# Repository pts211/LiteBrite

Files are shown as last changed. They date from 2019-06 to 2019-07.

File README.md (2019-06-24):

# LiteBrite

LiteBrite is a project created for Cerner's DevCon 2019. Its original purpose was to be an interactive piece at the conference for spectators to play with. In throwing around ideas it was determined we could build something that would allow for more uses in the future. This LiteBrite is more of an interactive display. 

# Contributers
  - Paul Sites (paul.sites@cerner.com)
  - Aaron Kaplan (aaron.kaplan@cerner.com)
 
  The Lee's Summit North FIRST Robotics team, The Broncobots:
  - Joshua Wentworth
  - Chuck Stephenson
 
  Good friend
  - James Sietz
  
  Cerner Associates
  - Hans Perera
  - Max Phillips
  - Caitie Oder
  - ... and more!

# Features
- Animated erasing 
- Ripple effect
- Image Viewer
- Desktop display
- Save/Load Designs
- Usage Recorder
- Playback of timelapsed usage
- Screensaver/power save
- e1.31 support (TBD)
- Idle notifications (TBD)
- "Button Mash" mini-game (TBD)
- Clock (TBD)

# Design Details
LiteBrite features:
- 912 individually addressible RGB LED's
- 912 Arcade buttons
- 24 Arduino Nano's
- 24 Custom 40 input circuit boards
- 3 Adafruit FadeCandy boards
- Unmanaged network switch
- Interactivity handled through Processing.

# Usage Details
- DevCon: 111,314 presses (60,912; 50, 402)
- Maker Faire: 332,135 presses (188,901; 143,234)

Lifetime: 443,449 peg presses!

# Acknowledgements
Paul Sites and Aaron Kaplan designed, manufactured, and built LiteBrite but it was only possible with a lot of support, both from inside and outside of Cerner. 

Special thanks to Joshua Wentworth, for working tirelessly alongside us the entire step of the way.

... TODO .. Add it all up

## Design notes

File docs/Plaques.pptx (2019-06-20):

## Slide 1

LiteBrite

Designed and built by Cerner Engineers with support from FRC Team #1987 for DevCon. DevCon is an annual engineering conference Cerner holds for associates to gather and share knowledge.

Click the clear button to start fresh
Press on pegs to change the color

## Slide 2

LiteBrite

  - 38 x 24 pixel arrangement (912 pixels total)
  - 5,472 hand soldered connections
  - 2,736 hand crimped connections
  - 14 days of 24/7 3d printing
  - 2,826 feet of wire
  - 912 arcade buttons
  - 238 feet of acrylic
  - 24 Arduino nano’s with ethernet shields
  - 24 custom designed PCB's
  - Custom welded frame
  - 2x unmanaged 16 port switches
  - Draws nearly 60A @ 5V when full white!
  - Designed to be used to interactively create images. However, can also load images, GIFs, and videos for display.

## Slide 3

Designed by
Paul Sites paul.sites@cerner.com
Aaron Kaplan aaron.kaplan@cerner.com
Joshua Wentworth
Built with help from
Nick Behrens nick.behrens@cerner.com
Pui Lam Cheng puilam.cheng@cerner.com
Miguel Fernandez miguel.fernandez@cerner.com
Taariq Imami taariq.imami@cerner.com
Caitie Oder caitie.oder@cerner.com
Hans Perera hans.perera@cerner.com
Max Philips max.philips@cerner.com
James Sietz
Jonathan Smith jonathan.smith@cerner.com
Melanie Taylor melanie.taylor@cerner.com
Christopher Thomas christopher.thomas@cerner.com
Brandon Wong brandon.wong@cerner.com

## Special Thanks

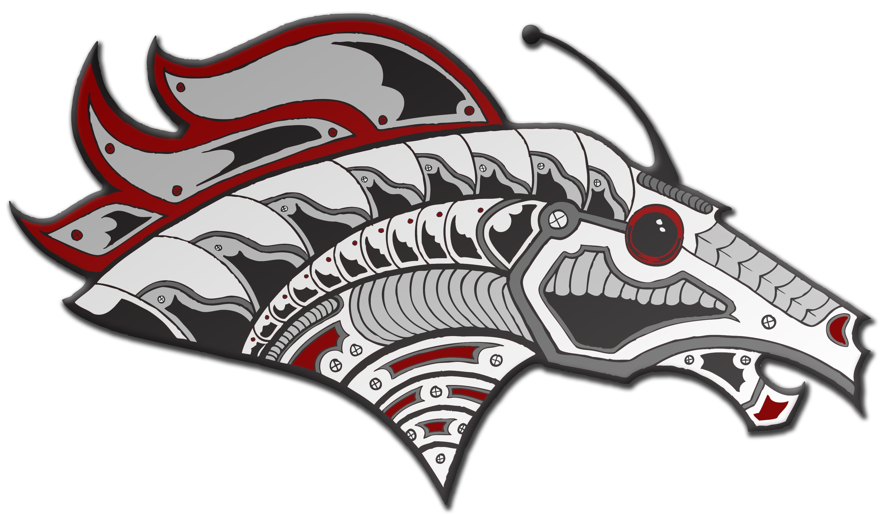
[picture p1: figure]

The Broncobots
FIRST Robotics Team #1987

For opening their robotics shop to build in, providing the tools and equipment necessary to manufacture, and team members to help with assembly.
www.teambroncobots.com

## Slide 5

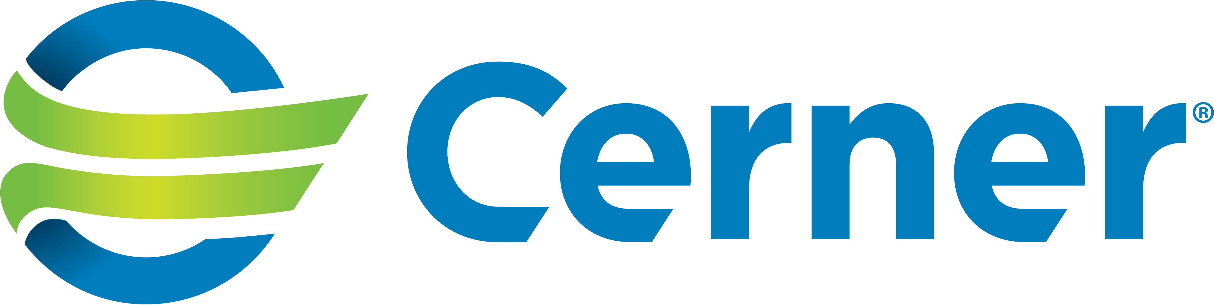
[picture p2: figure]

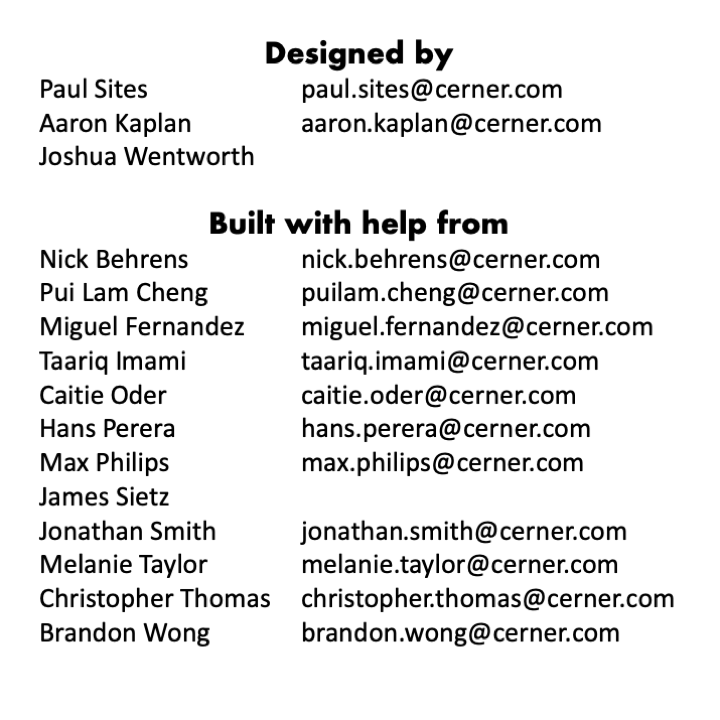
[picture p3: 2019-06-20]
docs/Plaques_updated/Plaques/Slide3.png

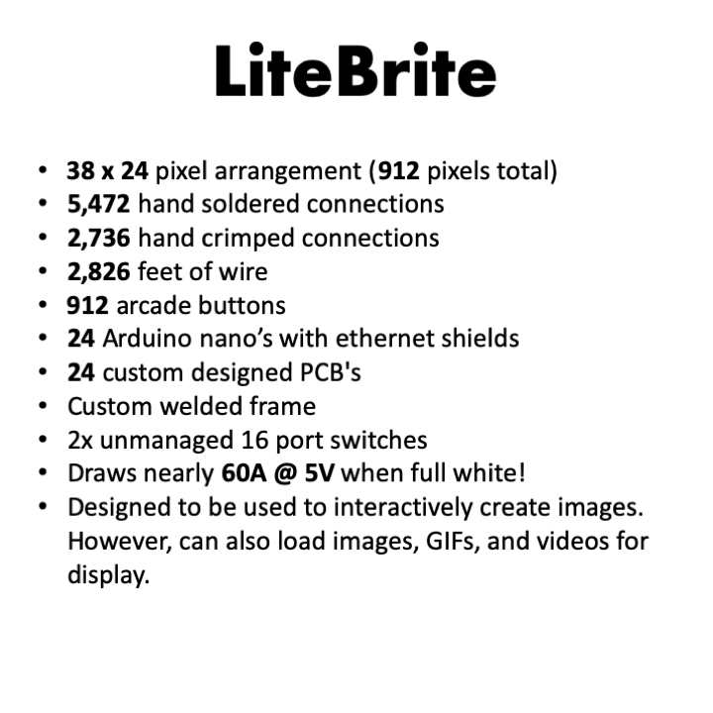
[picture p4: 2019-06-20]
docs/Plaques_updated/Plaques/Slide2.png

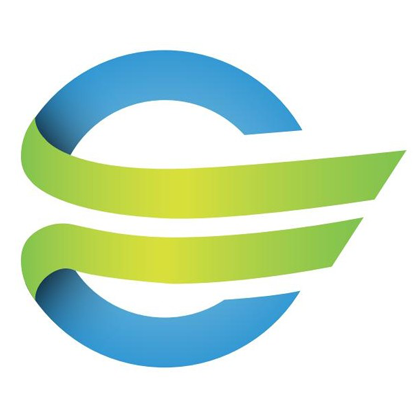
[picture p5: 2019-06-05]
Processing/ProcessingController/images/cern.png

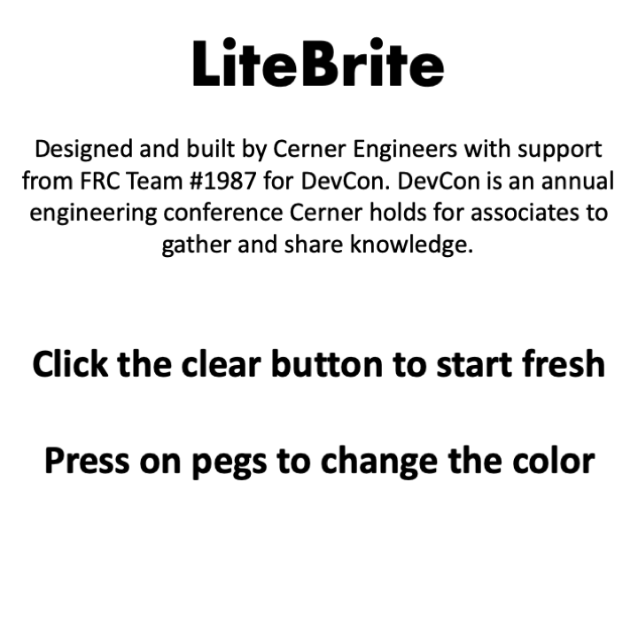
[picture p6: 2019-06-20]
docs/Plaques_updated/Plaques/Slide1.png

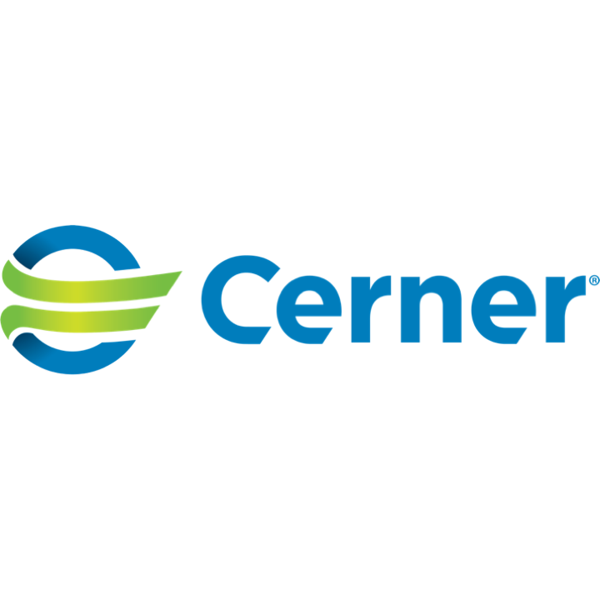
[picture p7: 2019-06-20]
docs/Plaques_updated/Plaques/Slide5.png

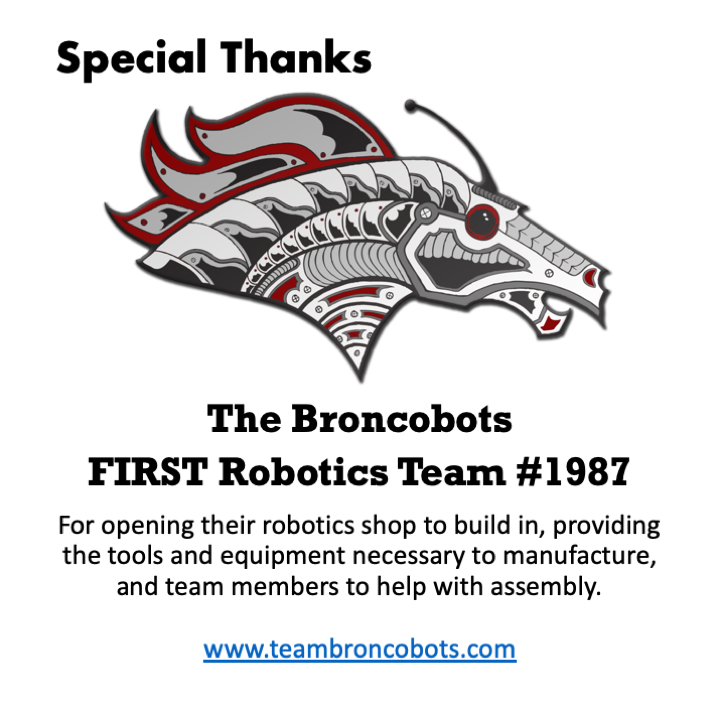
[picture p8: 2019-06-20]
docs/Plaques_updated/Plaques/Slide4.png

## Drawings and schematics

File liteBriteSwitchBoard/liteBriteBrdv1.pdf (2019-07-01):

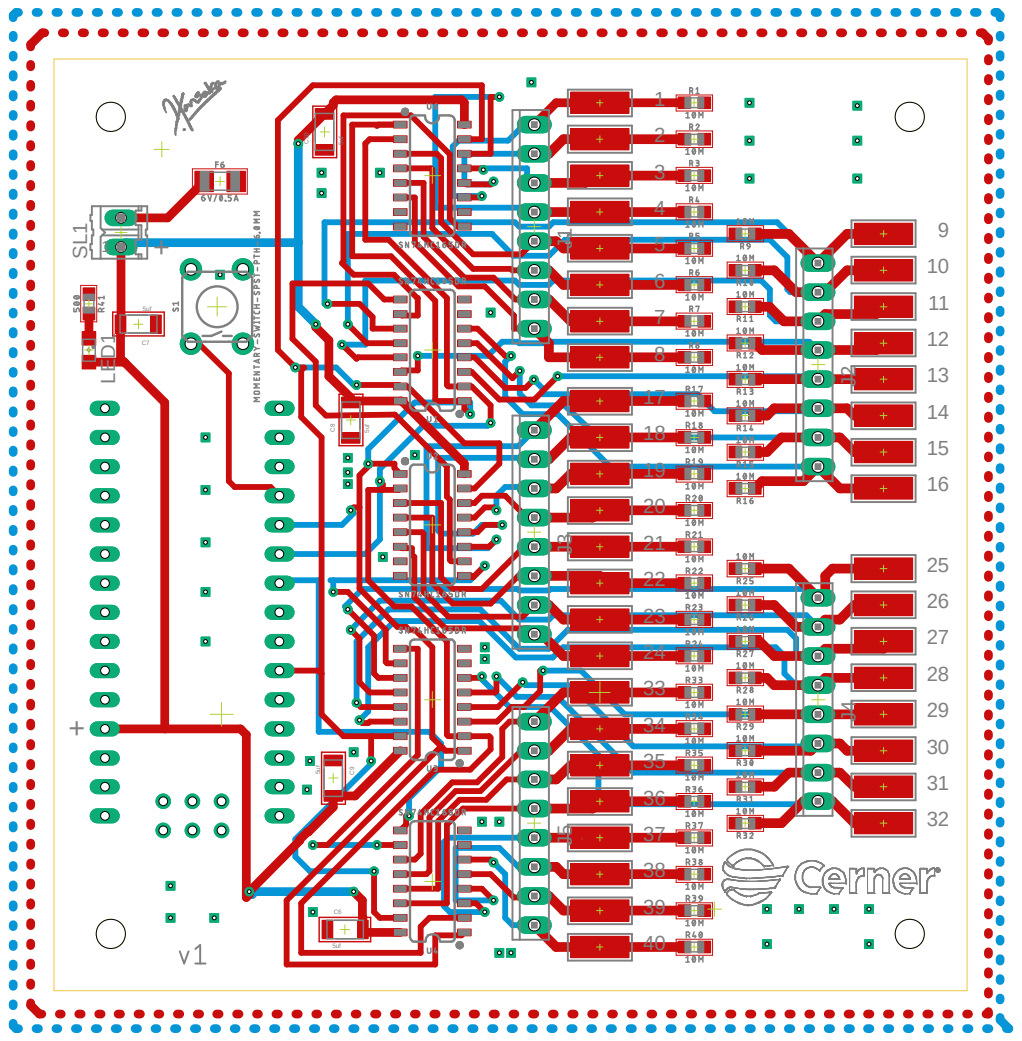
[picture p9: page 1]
343 C¹⁰; J4 J5 LED¹

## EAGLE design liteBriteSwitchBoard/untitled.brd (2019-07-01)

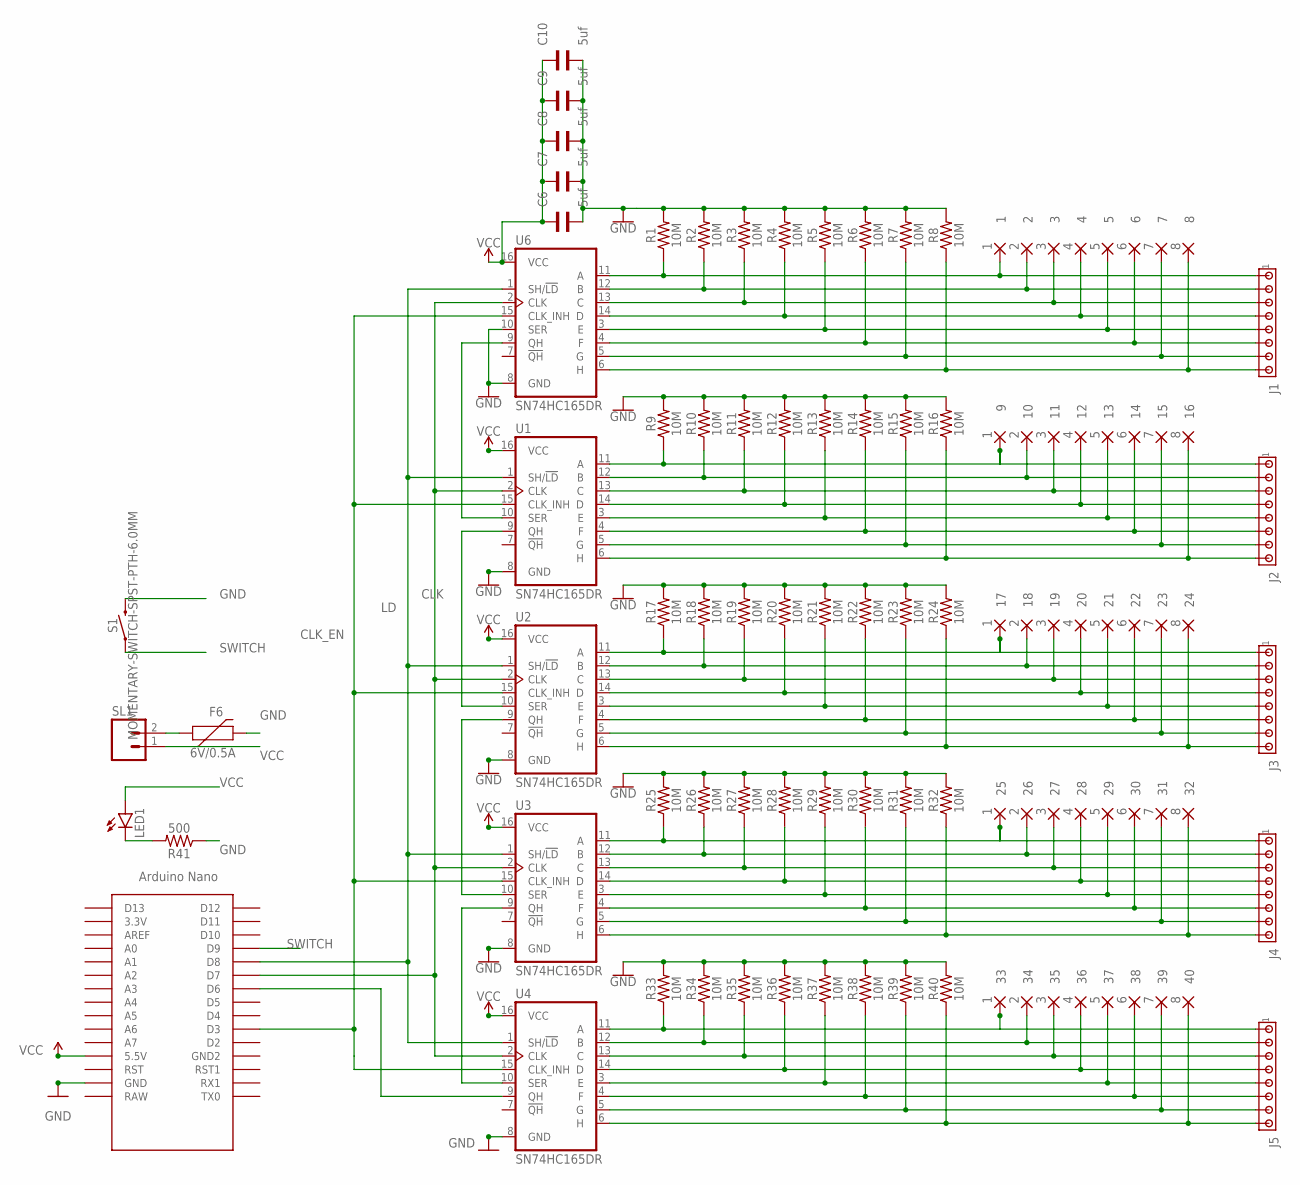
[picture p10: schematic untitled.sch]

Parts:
1, 9, 17, 25, 33: 1; 5-1,8
2, 10, 18, 26, 34: 2; 5-1,8
3, 11, 19, 27, 35: 3; 5-1,8
4, 12, 20, 28, 36: 4; 5-1,8
5, 13, 21, 29, 37: 5; 5-1,8
6, 14, 22, 30, 38: 6; 5-1,8
7, 15, 23, 31, 39: 7; 5-1,8
8, 16, 24, 32, 40: 8; 5-1,8
C6, C7, C8, C9, C10: 5uf; WCAP-CSGP_1206
F6: 6V/0.5A; 1206
J1, J2, J3, J4, J5: MTA08-100; 10X08MTA
LED1: LEDSML0805; SML0805
R1, R2, R3, R4, R5, R6, R7, R8, R9, R10, R11, R12, R13, R14, R15, R16, R17, R18, R19, R20, R21, R22, R23, R24, R25, R26, R27, R28, R29, R30, R31, R32, R33, R34, R35, R36, R37, R38, R39, R40: 10M; 0603
R41: 500; 0603
S1: MOMENTARY-SWITCH-SPST-PTH-6.0MM; TACTILE_SWITCH_PTH_6.0MM
SL1: M02; 02P
U1, U2, U3, U4, U6: SN74HC165DR; SO16
U$1: NANO

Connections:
B1: 2.1, J1.2, R2.1, U6.12 (B)
C1: 3.1, J1.3, R3.1, U6.13 (C)
CLK: U1.2 (CLK), U2.2 (CLK), U3.2 (CLK), U4.2 (CLK), U6.2 (CLK), U$1.D7
CLK_EN: U1.15 (CLK_INH), U2.15 (CLK_INH), U3.15 (CLK_INH), U4.15 (CLK_INH), U6.15 (CLK_INH), U$1.D3
D1: 4.1, J1.4, R4.1, U6.14 (D)
E1: 5.1, J1.5, R5.1, U6.3 (E)
F1: 6.1, J1.6, R6.1, U6.4 (F)
G1: 7.1, J1.7, R7.1, U6.5 (G)
GND: C6.1, C7.1, C8.1, C9.1, C10.1, F6.2, R1.2, R2.2, R3.2, R4.2, R5.2, R6.2, R7.2, R8.2, R9.2, R10.2, R11.2, R12.2, R13.2, R14.2, R15.2, R16.2, R17.2, R18.2, R19.2, R20.2, R21.2, R22.2, R23.2, R24.2, R25.2, R26.2, R27.2, R28.2, R29.2, R30.2, R31.2, R32.2, R33.2, R34.2, R35.2, R36.2, R37.2, R38.2, R39.2, R40.2, R41.1, S1.3 (2), U1.8 (GND), U2.8 (GND), U3.8 (GND), U4.8 (GND), U6.8 (GND), U6.10 (SER), U$1.GND
H1: 8.1, J1.8, R8.1, U6.6 (H)
LD: U1.1 (SH/!LD), U2.1 (SH/!LD), U3.1 (SH/!LD), U4.1 (SH/!LD), U6.1 (SH/!LD), U$1.D8
unnamed: U1.10 (SER), U6.9 (QH)
unnamed: U1.9 (QH), U2.10 (SER)
unnamed: U2.9 (QH), U3.10 (SER)
unnamed: U3.9 (QH), U4.10 (SER)
unnamed: 1.1, J1.1, R1.1, U6.11 (A)
unnamed: F6.1, SL1.2
unnamed: U4.9 (QH), U$1.D6
unnamed: LED1.C, R41.2
unnamed: 9.1, J2.1, R9.1, U1.11 (A)
unnamed: 10.1, J2.2, R10.1, U1.12 (B)
unnamed: 11.1, J2.3, R11.1, U1.13 (C)
unnamed: 12.1, J2.4, R12.1, U1.14 (D)
unnamed: 13.1, J2.5, R13.1, U1.3 (E)
unnamed: 14.1, J2.6, R14.1, U1.4 (F)
unnamed: 15.1, J2.7, R15.1, U1.5 (G)
unnamed: 16.1, J2.8, R16.1, U1.6 (H)
unnamed: 17.1, J3.1, R17.1, U2.11 (A)
unnamed: 18.1, J3.2, R18.1, U2.12 (B)
unnamed: 19.1, J3.3, R19.1, U2.13 (C)
unnamed: 20.1, J3.4, R20.1, U2.14 (D)
unnamed: 21.1, J3.5, R21.1, U2.3 (E)
unnamed: 22.1, J3.6, R22.1, U2.4 (F)
unnamed: 23.1, J3.7, R23.1, U2.5 (G)
unnamed: 24.1, J3.8, R24.1, U2.6 (H)
unnamed: 25.1, J4.1, R25.1, U3.11 (A)
unnamed: 26.1, J4.2, R26.1, U3.12 (B)
unnamed: 27.1, J4.3, R27.1, U3.13 (C)
unnamed: 28.1, J4.4, R28.1, U3.14 (D)
unnamed: 29.1, J4.5, R29.1, U3.3 (E)
unnamed: 30.1, J4.6, R30.1, U3.4 (F)
unnamed: 31.1, J4.7, R31.1, U3.5 (G)
unnamed: 32.1, J4.8, R32.1, U3.6 (H)
unnamed: 33.1, J5.1, R33.1, U4.11 (A)
unnamed: 34.1, J5.2, R34.1, U4.12 (B)
unnamed: 35.1, J5.3, R35.1, U4.13 (C)
unnamed: 36.1, J5.4, R36.1, U4.14 (D)
unnamed: 37.1, J5.5, R37.1, U4.3 (E)
unnamed: 38.1, J5.6, R38.1, U4.4 (F)
unnamed: 39.1, J5.7, R39.1, U4.5 (G)
unnamed: 40.1, J5.8, R40.1, U4.6 (H)
SWITCH: S1.1, U$1.D9
VCC: C6.2, C7.2, C8.2, C9.2, C10.2, LED1.A, SL1.1, U1.16 (VCC), U2.16 (VCC), U3.16 (VCC), U4.16 (VCC), U6.16 (VCC), U$1.5V (5.5V)

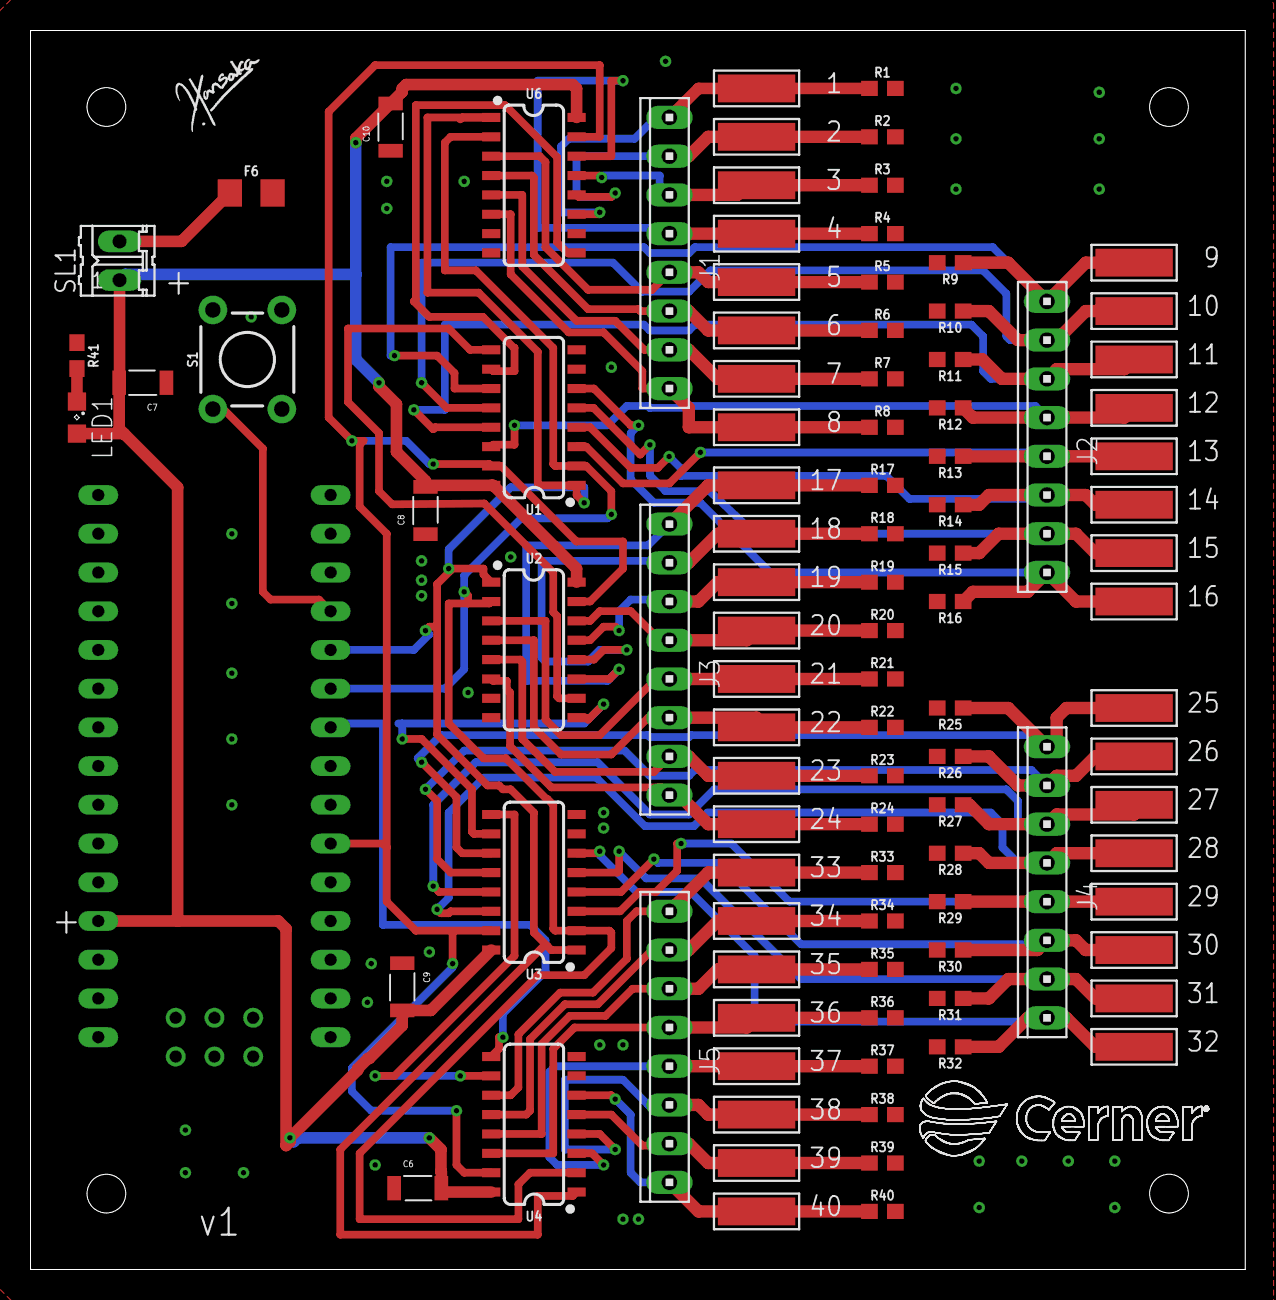
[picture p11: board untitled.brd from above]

Board: 2 copper layers, 79.7 x 81.3 mm, 107 parts (0 on the bottom side), 53 nets.

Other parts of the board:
U$2, U$3, U$4, U$5: DRILL_0.1000
U$6: SIGNATURE
U$7: CERNER

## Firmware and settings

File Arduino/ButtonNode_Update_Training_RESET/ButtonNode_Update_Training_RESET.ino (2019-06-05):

/* ButtonNode.ino
   Author: Paul Sites (paul.sites@cerner.com)

   This ButtonNode is part of the LiteBrite project, created for DevCon 2019. The LiteBrite, slotted to have 24 rows,
   will have an arduino per row. Each arduino is responsible for monitoring button input from 38 buttons and passing
   the data on to the main controller over UDP.

   The IP of each Arduino should represent the row that they are positioned on the LiteBrite, starting from the top at 1.
   The MAC address should be unique for each Arduino.
   The destination IP can either be a specific device IP, or a broadcast (255.255.255.255).
*/

#define ROW_NUMBER   10
boolean isTraining = false;

//The ROW_NUMBER will automatically configure the correct IP and unique MAC address.

#include <EEPROM.h>
#include <BitBool.h>

// ****************************************
// ****************************************
//        Network Configuration
// ****************************************
// ****************************************
#include <EtherCard.h>

static byte mymac[] = { 0x1A, 0x2B, 0x3C, 0x4D, 0x5E, ROW_NUMBER };
static byte myip[] = { 192, 168, 1, ROW_NUMBER };

//static byte srip[] = { 192, 168, 1, 100 }; // destination IP
static byte srip[] = { 255, 255, 255, 255 }; // destination IP
static byte gwip[] = { 192, 168, 1, 100 };
static byte dns[]  = { 192, 168, 1, 100 };
static byte mask[] = { 255, 255, 255, 0 }; //REQUIRED. Otherwise the DST MAC won't be specified.

const int dstPort PROGMEM = 6000;
const int srcPort PROGMEM = 6000;

const bool useDHCP PROGMEM = false;

byte Ethernet::buffer[700];
static uint32_t timer;

// ****************************************
// ****************************************
//        Shift Register Configuration
// ****************************************
// ****************************************

// How many shift register chips are daisy-chained.
#define NUMBER_OF_SHIFT_CHIPS   5

//Width of data (how many ext lines).
#define DATA_WIDTH   NUMBER_OF_SHIFT_CHIPS * 8

#define NUM_ACTIVE_INPUTS 39

// Width of pulse to trigger the shift register to read and latch.
#define PULSE_WIDTH_USEC   5

//Optional delay between shift register reads.
#define POLL_DELAY_MSEC   10      //TODO 5/29 increased from 1ms. Going to see if that helps the double hit.
#define BYTES_VAL_T unsigned long


int configPin        = 9;  // Connects to the Clock pin the 1

int ploadPin        = 8;  // Connects to Parallel load pin the 165
int clockEnablePin  = 3;  // Connects to Clock Enable pin the 165
int dataPin         = 6;  // Connects to the Q7 pin the 165
int clockPin        = 7;  // Connects to the Clock pin the 165

BYTES_VAL_T tempPinValues;
BYTES_VAL_T deltaPinValues;
BYTES_VAL_T oldDeltaPinValues;
BYTES_VAL_T pinValues;
BYTES_VAL_T oldPinValues;

BitBool<DATA_WIDTH> tempPinValuesB;
BitBool<DATA_WIDTH> deltaPinValuesB;
BitBool<DATA_WIDTH> oldDeltaPinValuesB;
BitBool<DATA_WIDTH> pinValuesB;
BitBool<DATA_WIDTH> oldPinValuesB;



int activeMappingIndex = 0;
byte buttonMapping[DATA_WIDTH];
String calibrationString = "00000000000000000000000000000000000000";//String(DATA_WIDTH, '0');

bool alternate = false;

BitBool<DATA_WIDTH> pXOR(BitBool<DATA_WIDTH> x, BitBool<DATA_WIDTH> y)
{
  BitBool<DATA_WIDTH> result;
  for (int i = 0; i < DATA_WIDTH; i++)
  {
    if ( x[i] ^ y[i] ) {
      result[i] = true;
    } else {
      result[i] = false;
    }
  }
  return result;
}

BitBool<DATA_WIDTH> pAND(BitBool<DATA_WIDTH> x, BitBool<DATA_WIDTH> y)
{
  BitBool<DATA_WIDTH> result;
  for (int i = 0; i < DATA_WIDTH; i++)
  {
    if ( x[i] & y[i] ) {
      result[i] = true;
    } else {
      result[i] = false;
    }
  }
  return result;
}

void initMapping()
{
  for (int i = 0; i < DATA_WIDTH; i++)
  {
    buttonMapping[i] = i;
  }
}

void printButtonMapping()
{
  for (int i = 0; i < DATA_WIDTH; i++)
  {
    Serial.println("Input[" + String(i) + "] == button[" + buttonMapping[i] + "]");
  }
}

void startButtonTraining()
{

}

String generateCalibrationString(int index)
{
  //Serial.print("DATA_WIDTH: ");
  //Serial.println(DATA_WIDTH);
  String output = "";
  for (int i = 0; i < DATA_WIDTH; i++)
  {
    if (index == -1) {
      output += "1";
    } else {
      output += (i == index) ? "1" : "0";
    }

  }
  //output += "c";
  return output;
}

void endButtonTraining()
{
  isTraining = false;
  Serial.println(F("Mapping complete."));
  printButtonMapping();
  saveButtonMapping();
}

void readButtonMapping()
{
  Serial.println(F("Config: Reading mapping."));

  if ( EEPROM.read ( 0 ) != 0xff ) {
    for (int i = 0; i < DATA_WIDTH; ++i )
      buttonMapping [ i ] = EEPROM.read ( i );
  }
  Serial.println(F("Config: Read."));
}

void saveButtonMapping()
{
  Serial.println(F("Config: Saving mapping."));
  int eeAddress = 0;   //Location we want the data to be put.
  for ( int i = 0; i < DATA_WIDTH; ++i ) {
    EEPROM.write ( i, buttonMapping [ i ] );
  }
  Serial.println(F("Config: Saved."));
}

void setup () {
  Serial.begin(9600);

  Serial.println(F("ButtonNode: Starting..."));

  initNetworking();
  initShiftRegisters();


  initMapping();
  printButtonMapping();
  //saveButtonMapping();

  readButtonMapping();

  printButtonMapping();

  Serial.println(F("ButtonNode: Ready."));

}

void initNetworking()
{
  Serial.println(F("ButtonNode: Initializing Network."));
  if (ether.begin(sizeof Ethernet::buffer, mymac, SS) == 0) {
    Serial.println( F("Failed to access Ethernet controller"));
  }

  if (!useDHCP || !ether.dhcpSetup()) {
    if (useDHCP) {
      Serial.println(F("DHCP failed. Setting static ip."));
    }
    ether.staticSetup(myip, gwip, dns, mask);
  }

  char mac_cstr[17];
  ether.makeNetStr(mac_cstr, mymac, sizeof(mymac), ':', 16);
  Serial.println("\tMAC: " + String(mac_cstr));
  ether.printIp("\tIP:  ", ether.myip);
  ether.printIp("\tGW:  ", ether.gwip);
  ether.printIp("\tDNS: ", ether.dnsip);

  //if (!ether.dnsLookup(website))
  //  Serial.println("DNS failed");
  //ether.printIp("SRV: ", ether.hisip);
}

void initShiftRegisters()
{
  Serial.println(F("ButtonNode: Initializing Buttons."));
  // Initialize our digital pins
  pinMode(ploadPin, OUTPUT);
  pinMode(clockEnablePin, OUTPUT);
  pinMode(clockPin, OUTPUT);
  pinMode(dataPin, INPUT);

  pinMode(configPin, INPUT);
  digitalWrite(configPin, HIGH);

  digitalWrite(clockPin, LOW);
  digitalWrite(ploadPin, HIGH);

  // Read in the pin states at startup.
  read_shift_regs();
  //oldPinValues = pinValues;
  oldDeltaPinValuesB = deltaPinValuesB;
}

//char textToSend[] = "01010101010101010101010101010101010101";
char textToSend[DATA_WIDTH];

void loop () {

  checkConfigButton();
  //REQUIRED. Handles low level network responses. Part of the MAC address fix.
  ether.packetLoop(ether.packetReceive());

  // Read the state of all zones.
  read_shift_regs();


  /*
     Since it is possible that multiple buttons in the same row could be pressed
     at the same time - more specifically, a new button could be pressed while another butting
     was already pressed - it is important to only send the change, delta, of the button states over
     the network.

     To do this we will only care when a button transistions from 0->1, ignoring when the button is released.

     We want to avoid:
     Frame 1: 00000000000000000000000000000000000001
     Frame 2: 00000000000000000000000000000000000101
     and instead send:
     Frame 1: 00000000000000000000000000000000000001
     Frame 2: 00000000000000000000000000000000000100
     In both scenarios, two buttons are pressed in Frame 2.

  */
  /*
     If I XOR previousVals and currentVals, then AND result and currentVals we will get ony the change to a pressed state.
     Threw a little demo sketch together to verify. https://code.sololearn.com/c40x3N2NWcIr/#py
  */

  //tempPinValuesB = pinValuesB ^ oldPinValuesB;  // XOR the old and new
  tempPinValuesB = pXOR(pinValuesB, oldPinValuesB);  // XOR the old and new

  //deltaPinValuesB = tempPinValuesB & pinValuesB;// AND the new and xor'd value to get only the changes to 1
  deltaPinValuesB = pAND(tempPinValuesB, pinValuesB);// AND the new and xor'd value to get only the changes to 1's.


  //tempPinValues = pinValues ^ oldPinValues;  // XOR the old and new
  //deltaPinValues = tempPinValues & pinValues;// AND the new and xor'd value to get only the changes to 1's.

  /*
    // TODO REMOVE This should be UNNEEDED thanks to bitwise operators. Keeping around just in case I need a backup.
    long currentBitVal;
    long previousBitVal;
    for (int i = 0; i < DATA_WIDTH; i++)
    {
    currentBitVal = (pinValues >> i);
    previousBitVal = (oldPinValues >> i);

    if(currentBitVal == previousBitVal){
      deltaPinValues |= (0 << ((DATA_WIDTH - 1) - i));
    }
    else if( (currentBitVal != previousBitVal) && currentBitVal){
      deltaPinValues |= (1 << ((DATA_WIDTH - 1) - i));
    }
    }
  */

  /*
    String pinValsStr = create_pin_values_string(pinValues);
    String deltaPinValsStr = create_pin_values_string(deltaPinValues);
    String oldDeltaPinValsStr = create_pin_values_string(oldDeltaPinValues);
    Serial.println("pins:      " + pinValsStr);
    Serial.println("delVal:    " + deltaPinValsStr);
    Serial.println("oldDelVal: " + oldDeltaPinValsStr);
  */
  boolean hasChanged = false;
  for (int i = 0; i < DATA_WIDTH; i++)
  {
    if ( deltaPinValuesB[i] != oldDeltaPinValuesB[i] ) {
      hasChanged = true;
      break;
    }
  }

  if (hasChanged)
  {
    //We only want to broadcast data out if we are on a rising edge of a change.
    //Make sure that we are sending a toggle.



    if (isTraining)
    {
      String deltaPinValsStr = create_pin_values_stringB(deltaPinValuesB);
      if (deltaPinValsStr.indexOf('1') >= 0) {
        //Serial.println(F("SIGNIFICANT"));

        train(deltaPinValsStr);
        /*
          buttonMapping[activeMappingIndex++] = deltaPinValsStr.indexOf('1');
          if (activeMappingIndex == DATA_WIDTH) {
          //Configuration complete.
          endButtonTraining();
          }
        */
      } else {
        //Serial.println(F("INSIGNIFICANT"));
      }

    } else {
      String deltaPinValsStr = create_pin_values_stringB_calib(deltaPinValuesB);
      if (deltaPinValsStr.indexOf('1') >= 0) {
        //Serial.println(F("SIGNIFICANT"));
        deltaPinValsStr.toCharArray(textToSend, DATA_WIDTH);
        ether.sendUdp(textToSend, sizeof(textToSend), srcPort, srip, dstPort );
      }
      else {
        //Serial.println(F("INSIGNIFICANT"));
      }
    }

    //Serial.println(" change detected.");

    oldPinValuesB = pinValuesB;
    oldDeltaPinValuesB = deltaPinValuesB;
  }

  hasChanged = false;
  for (int i = 0; i < DATA_WIDTH; i++)
  {
    if ( pinValuesB[i] != oldPinValuesB[i] ) {
      hasChanged = true;
      break;
    }
  }

  if (hasChanged)
  {
    oldPinValuesB = pinValuesB;
  }

  // If there was a chage in state, display which ones changed.

  //TODO REMOVE This is the old logic that broadcasts all state changes. Removal pending
  //testing of new methods.
  /*
    if (pinValues != oldPinValues)
    {
    String pinValsStr = create_pin_values_string(pinValues);

    Serial.print("Pin value change detected: ");
    Serial.println(pinValsStr);

    pinValsStr.toCharArray(textToSend, DATA_WIDTH);
    ether.sendUdp(textToSend, sizeof(textToSend), srcPort, srip, dstPort );

    oldPinValues = pinValues;
    }
  */
  /*
    //TODO DEBUG Helpful for checking that packets are making it to their destination.
    if (millis() > timer) {
      timer = millis() + 4000;

      Serial.print("Sending to server at: ");
      Serial.println(ipToString(srip));

     //static void sendUdp (char *data,uint8_t len,uint16_t sport, uint8_t *dip, uint16_t dport);
     ether.sendUdp(textToSend, sizeof(textToSend), srcPort, srip, dstPort );
    }
  */

  if (isTraining && (millis() > timer) ) {
    timer = millis() + 250;

    calibrationString = generateCalibrationString(activeMappingIndex);
    if (alternate) {
      calibrationString += "c";
    }
    alternate = !alternate;



    //Serial.print(F("Sending calibration string: "));
    //Serial.println(calibrationString);
    //Serial.println(ipToString(srip));

    char calibrationTextToSend[calibrationString.length() + 2];

    calibrationString.toCharArray(calibrationTextToSend, calibrationString.length() + 1);
    ether.sendUdp(calibrationTextToSend, sizeof(calibrationTextToSend), srcPort, srip, dstPort );
  }



  delay(POLL_DELAY_MSEC);

}



void train(String deltaPinValsStr)
{
  buttonMapping[activeMappingIndex] = deltaPinValsStr.indexOf('1');



  activeMappingIndex++;

  if (activeMappingIndex >= NUM_ACTIVE_INPUTS) {

    calibrationString = generateCalibrationString(-1);

    char calibrationTextToSend[calibrationString.length() + 1];

    calibrationString.toCharArray(calibrationTextToSend, calibrationString.length());
    ether.sendUdp(calibrationTextToSend, sizeof(calibrationTextToSend), srcPort, srip, dstPort );

    //Configuration complete.
    endButtonTraining();
  } else {
    calibrationString = generateCalibrationString(activeMappingIndex);

    Serial.print("Sending calibration string: ");
    Serial.println(calibrationString);
    //Serial.println(ipToString(srip));

    char calibrationTextToSend[calibrationString.length() + 1];

    calibrationString.toCharArray(calibrationTextToSend, calibrationString.length());
    ether.sendUdp(calibrationTextToSend, sizeof(calibrationTextToSend), srcPort, srip, dstPort );

  }
}




// ****************************************
// ****************************************
//        Networking Methods
// ****************************************
// ****************************************

String ipToString(byte ip[4])
{
  return String(ip[0]) + "." + String(ip[1]) + "." + String(ip[2]) + "." + String(ip[3]);
}

// ****************************************
// ****************************************
//        Shift Register Methods
// ****************************************
// ****************************************

/* This function is essentially a "shift-in" routine reading the
   serial data from the shift register chips and representing
   the state of those pins in an unsigned integer (or long).
*/
void read_shift_regs()
{
  /* Trigger a parallel Load to latch the state of the data lines,
  */
  digitalWrite(clockEnablePin, HIGH);
  digitalWrite(ploadPin, LOW);
  delayMicroseconds(PULSE_WIDTH_USEC);
  digitalWrite(ploadPin, HIGH);
  digitalWrite(clockEnablePin, LOW);

  /* Loop to read each bit value from the serial out line
     of the SN74HC165N.
  */
  for (int i = 0; i < DATA_WIDTH; i++)
  {
    /* Set the corresponding bit in bytesVal.
    */
    pinValuesB[i] = digitalRead(dataPin);

    /* Pulse the Clock (rising edge shifts the next bit).
    */
    digitalWrite(clockPin, HIGH);
    delayMicroseconds(PULSE_WIDTH_USEC);
    digitalWrite(clockPin, LOW);
  }
}

String tempStr = "";
String create_pin_values_string(BYTES_VAL_T values)
{
  tempStr = "";
  for (int i = 0; i < DATA_WIDTH; i++)
  {
    //Test simplifying.
    tempStr += ((values >> i) & 1) ? "1" : "0";
  }
  return tempStr;
}

String create_pin_values_stringB(BitBool<DATA_WIDTH> values)
{
  tempStr = "";
  for (int i = 0; i < DATA_WIDTH; i++)
  {
    //Test simplifying.
    tempStr += values[i] ? "1" : "0";
  }
  return tempStr;
}

String create_pin_values_stringB_calib(BitBool<DATA_WIDTH> values)
{
  tempStr = "";
  for (int i = 0; i < DATA_WIDTH; i++)
  {
    //Test simplifying.
    tempStr += values[ buttonMapping[i] ] ? "1" : "0";
  }
  return tempStr;
}

void display_pin_values()
{
  Serial.print("Pin States:\r\n");

  for (int i = 0; i < DATA_WIDTH; i++)
  {
    Serial.print("  Pin-");
    Serial.print(i);
    Serial.print(": ");

    if (pinValuesB[i])
      Serial.print("HIGH");
    else
      Serial.print("LOW");

    Serial.print("\r\n");
  }

  Serial.print("\r\n");
}
//END SHIFTY STUFF

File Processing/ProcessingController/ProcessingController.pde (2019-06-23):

/* ProcessingController
 * Author: Paul Sites (paul.sites@cerner.com)
 * 
 *
 * This is software used to control the LiteBrite created for DevCon 2019.
 */
//Display Size 
final int SCREEN_WIDTH = 900;
final float ASPECT_RATIO = float(PegGrid.GRID_W)/float(PegGrid.GRID_H);

//Port to listen to for button presses.
final int INPUT_PORT = 6000;


Configuration config;

//Desktop Display
import java.awt.Robot;
import java.awt.image.BufferedImage;
import java.awt.Rectangle;

import java.nio.*;
import java.nio.file.Path;
import java.nio.file.Paths;
import java.nio.file.Files;

// import UDP library
import hypermedia.net.*;
import gifAnimation.*;
// Need G4P library
import g4p_controls.*;
// You can remove the PeasyCam import if you are not using
// the GViewPeasyCam control or the PeasyCam library.
import peasy.*;

PegGrid grid;

UDP udp;  // Receive button presses over UDP.
OPC opc;  // Connect to FadeCandy lights via OPC.

//Store a few default transistions.
AnimatedTransistion pac;
Gif pacman;
AnimatedTransistion blink;
Gif blinky;
Gif coffee;

//Image loading
int currentImg = -1;
boolean hasDrawn = false;
List<PImage> imgs;

//Ripples
RippleGenerator ripGen;

//Desktop Viewer
DesktopViewer desktop;

//Loading Sequence
LoadingBar loadingBar;

//Scrolling Text
ScrollingText title;

//GhostPegGrid - This peg grid is not persisted to the display. It is just an overlay. 
GhostPegGrid ghostGrid;


GridRecorder recorder;

//Recording playback
PlaybackManager playManager;
Playback player;

Clock clock;
Timer idleTimer;
Timer shortIdleTimer;
Timer workDisplayTimer;

void settings() {
  size(SCREEN_WIDTH, int(SCREEN_WIDTH/ASPECT_RATIO)); //Don't even think about doing a print statement before this.
}

void setup()
{
  colorMode(RGB, 100);
  //frameRate(30);
  println("Controller: Initializing Display Parameters. Done.");  
  grid = new PegGrid(this, "127.0.0.1", 7890);

  config = new Configuration();

  clock = new Clock();

  idleTimer = new Timer(config.IDLE_TIMEOUT, config.IDLE_TIMEOUT_UNIT);
  idleTimer.start();

  shortIdleTimer = new Timer(config.SHORT_IDLE_TIMEOUT, config.SHORT_IDLE_TIMEOUT_UNIT);
  shortIdleTimer.start();

  workDisplayTimer = new Timer(config.WORKDISPLAY_TIMEOUT, config.WORKDISPLAY_TIMEOUT_UNIT);

  initNetworking();
  loadImages();
  loadGifs();

  //Ripples
  ripGen = new RippleGenerator(400);

  createGUI();
  customGUI();

  desktop = new DesktopViewer(SCREEN_WIDTH, int(SCREEN_WIDTH/ASPECT_RATIO));

  loadingBar = new LoadingBar();

  ghostGrid = new GhostPegGrid();
  ghostGrid.setPegs(grid.getPegs());

  recorder = new GridRecorder();
  recorder.setPegs(grid.getPegs());


  playManager = new PlaybackManager();
  playManager.listFiles();
  playManager.setRandomIndex();

  player = new Playback(playManager.getActiveFilePath());
  player.setPegs(grid.getPegs());




  //config.loadingSequenceEnabled = true;
  //startLoadingSequence();

  title = new ScrollingText();

  startEffectTimers();
}

void initNetworking()
{
  println("Controller: Initializing Network.");
  //Configure network.

  udp = new UDP( this, INPUT_PORT);
  udp.log( true );     // <-- printout the connection activity
  udp.listen( true );
  println("Controller: Initializing Network. Done.");
  println("Controller: Initializing Network. Done.");
}

void loadImages()
{
  println("Controller: Loading Images.");
  //Image loading
  //String path = "/home/robot/Desktop/LiteBrite/Processing/ProcessingController/images";
  String path = dataPath("../images");
  println("\tpath: " + path);
  String[] filenames = listFileNames(path);
  printArray(filenames);


  imgs = new ArrayList();
  for (int i = 0; i < filenames.length; i++) {
    String filename = filenames[i].toUpperCase();
    if ( filename.contains(".JPG") 
      || filename.contains(".PNG") 
      || filename.contains(".GIF") ) {
      imgs.add(loadImage(path+"/"+filenames[i]));
    }
  }
  println("Controller: Loading Images. Done.");
}

void loadGifs()
{
  pacman = new Gif(this, dataPath("../animated/pacman-animation-crop-tail.gif"));
  pac = new AnimatedTransistion(pacman, 3, false);

  blinky = new Gif(this, dataPath("../animated/blinky-animation-crop.gif"));
  blink = new AnimatedTransistion(blinky, 3, true);

  coffee = new Gif(this, dataPath("../animated/coffee_crop_invert_wide.gif"));
  coffee.loop();  
  coffee.play();
}

void draw()
{
  if ( shortIdleTimer.update() ) {
    if ( pressesSinceIdle < config.MIN_ACTIVITY ) {
      config.isIdle = true;
    }
    //println("pressesSinceIdle: " + pressesSinceIdle);
  }

  if (idleTimer.update()) {
    updatePlayback();
    config.isIdle = true;
  }
  if (config.isIdle) {
    clock.processTriggers();
  }
  if (config.isSleeping)
  {
    background(0);
    return;
  }


  background(0);
  grid.draw();

  if (pac.isPlaying()) {
    pac.draw();
    grid.loadImg();
  }

  if (blink.isPlaying()) {
    blink.draw();
    grid.loadImg();
  }

  //We only want to draw the image to the screen once to load the image data into
  //the pegs. That way the image can be changed by clicking a peg.
  if (currentImg != -1 && !hasDrawn) {
    grid.setAllOff();
    //If we load a saved LiteBrite image then we don't ant to scale it.
    PImage img = imgs.get(currentImg);
    img.resize(width, height);

    imageMode(CENTER);
    image(img, width/2, height/2);
    hasDrawn = true; 
    grid.loadImg();
  }


  if (config.rippleEnabled) {
    ripGen.draw();
  }
  if (config.showDesktop) {
    processIdleTimers();
    desktop.draw();
  }
  if (config.randomPegsEnabled) {
    processIdleTimers();
    randomPegs();
  }
  if (config.loadingSequenceEnabled) {
    processIdleTimers();
    loadScreen();
  }
  if (config.rainbowEnabled) {
    processIdleTimers();
    rainbowCycle();
  }
  if (config.playbackEnabled) {
    processIdleTimers();
    player.draw();
  }

  if (config.isMorning && config.isIdle)
  {
    image(coffee, width/2  - coffee.width*3/2, height / 2 - coffee.height*3/2, coffee.width * 3, coffee.height * 3);
  } else if ( config.isIdle )
  {
    //randomPegsScreensaver();
    //ghostGrid.draw();
    workPlaybackScreensaver();
  }

  title.draw();
  tf_playbackDir.setText(playManager.getActiveFileName());
}

boolean processIdleTimers()
{

  shortIdleTimer.reset();
  idleTimer.reset();
  if (config.isIdle || config.isSleeping) {
    config.isIdle = false;
    config.isSleeping = false;

    pressesSinceIdle = 0;
    recorder.captureWake();
    return true;
  }
  pressesSinceIdle++;



  return false;
}
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

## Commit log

2019-05-14 Updated ButtonNode to handle sending buttons over network.
2019-05-14 Tidying up ButtonNode
2019-05-14 Updated logic to only send changes of button state to pressed.
2019-05-14 FIXED THE UDP PROBLEM!!! Turns out UDP consumers typically like the destination MAC address populated. Wouldn't you know it, the EtherCard library doesn't send the desination MAC in a lot of scenario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
    [ButtonNode.ino]
2019-05-14 Updated ButtonNode for easy mass deployment. Added documentation.
2019-05-22 v1 board
    [untitled.brd, untitled.sch]
2019-05-31 Fixed corrupted G4P configuration.
    [PegGrid.pde, gui.pde]
2019-06-01 Fixed button logic.
2019-06-02 Updated button logic data types. Can now read from all the buttons!
2019-06-04 Initial button calibration working. Still need to save to EEPROM.
2019-06-04 Finished Arduino Software. General updates.
2019-06-10 Updated with screensaver and corrected CSV file writing.
    [Configuration.pde, Effects.pde, Peg.pde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]
2019-06-12 Added walk by timeout. Updated timer logic. Updated logging.
    [recording_20190612_091653.csv]
2019-06-20 Updating wtih latest timelapse data and LiteBrite settings
    [recording_20190612_091653.csv]
2019-06-23 Adding maker faire day 01 data. Fixed ripple.
    [Configuration.pde, PegGrid.pde, ProcessingController.pde]
2019-07-01 Adding last weeks recordings. Corrected issue with folder naming.
    [GridRecorder.pde]

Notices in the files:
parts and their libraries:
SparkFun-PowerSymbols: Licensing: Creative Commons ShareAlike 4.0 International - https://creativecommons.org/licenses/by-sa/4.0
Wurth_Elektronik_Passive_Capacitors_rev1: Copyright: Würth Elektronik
